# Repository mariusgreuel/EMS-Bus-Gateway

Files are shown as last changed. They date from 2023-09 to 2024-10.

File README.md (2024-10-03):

# EMS Bus Gateway

This repository contains a schematic and PCB layout of an **EMS Bus Gateway**. With the EMS Bus Gateway and the [EMS-ESP32](https://github.com/mariusgreuel/EMS-ESP32) firmware, you can connect EMS Bus devices, such as the **Buderus Logamax** boilers to your home automation system.

## Introduction

The assembled EMS Bus Gateway consists of three essential components:

- A voltage level converter that converts the EMS bus voltage levels to 3.3V TTL levels.
- A micro-controller.
- The EMS-ESP32 firmware.

The schematic uses a modified level convertor from the EMS reference schematic circulating the internet. For the micro-controller, a $5 [Seeed Studio XIAO ESP32C3](https://www.seeedstudio.com/Seeed-XIAO-ESP32C3-p-5431.html) board is used. The micro-controller needs to be programmed with [EMS-ESP32](https://github.com/mariusgreuel/EMS-ESP32) firmware, which is capable of decoding the EMS bus protocol and broadcasting the EMS parameters into your network via MQTT. Finally, the assembled board may be fitted into a **Hammond 1551KGY** enclosure.

The assembled EMS Bus Gateway board looks like this:

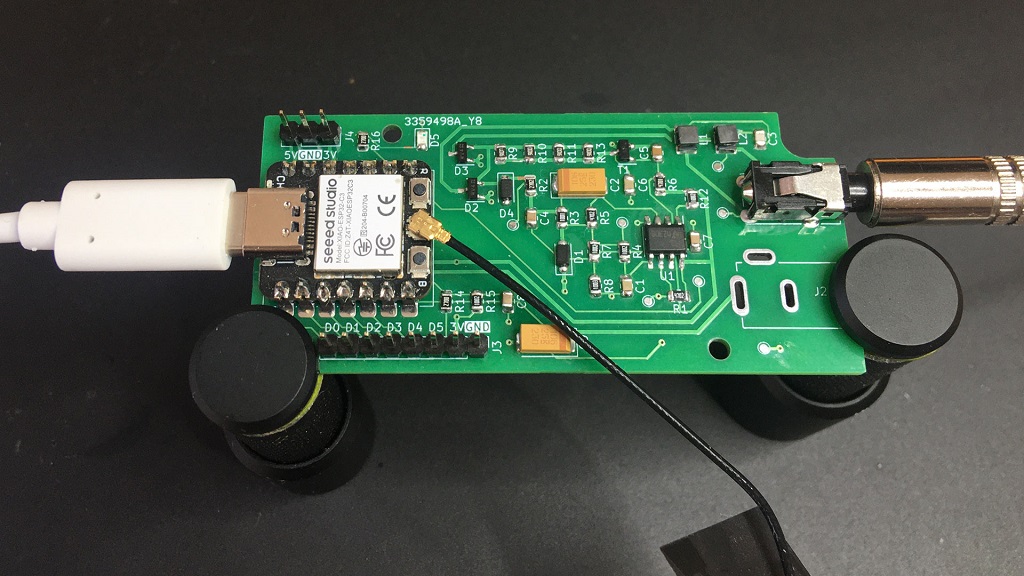
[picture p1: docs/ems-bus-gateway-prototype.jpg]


## EMS Bus Background

Many Buderus devices, such as the **Buderus Logamax plus GB132 T** boiler, use a bus system called **EMS (Energy Management System)** to communicate with other devices, such as the RC30 room controller. The EMS bus is a simple two-wire serial bus that uses voltage/current modulation to transmit data. With the proper hardware and software, you can transmit many parameters of your boiler into your home automation system.

For instance, you could use [Home Assistant](https://www.home-assistant.io/) to monitor the temperatures of your boiler. Here is a screenshot showing the relevant boiler temperatures during a 10 minutes heating interval:

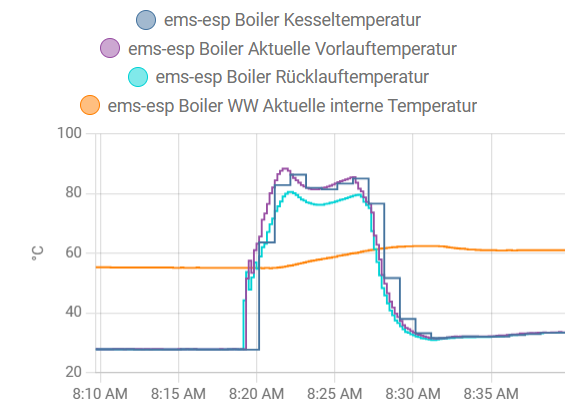
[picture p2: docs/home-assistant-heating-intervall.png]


## Build the EMS-ESP32 firmware

To build the EMS-ESP32 firmware, we use the **PlatformIO** toolchain. Please refer to the [PlatformIO documentation](https://docs.platformio.org/en/latest/) on how to install and use **PlatformIO**. According to the original author of the EMS-ESP32 firmware, your should build the firmware on Linux.

Instead of building the firmware locally, you may download pre-built binaries from my [EMS-ESP32 Releases](https://github.com/mariusgreuel/EMS-ESP32/releases).

To setup the **PlatformIO** toolchain, run the following commands in a Linux bash:

```bash
sudo apt install python3
python3 -m venv ~/.venv/ems-esp32
source ~/.venv/ems-esp32/bin/activate
curl -o- https://raw.githubusercontent.com/nvm-sh/nvm/v0.40.1/install.sh | bash
python -m pip install --upgrade pip
pip install platformio
pip install esptool
nvm install 18
nvm use 18
npm install --global yarn
git clone https://github.com/mariusgreuel/ems-esp32.git -b xiao-3.6.5 ~/repos/ems-esp32
```

To build the EMS-ESP32 firmware for a **XIAO ESP32C3**, run the following command:

```bash
source ~/.venv/ems-esp32/bin/activate
nvm use 18
cd ~/repos/ems-esp32
git clean -xdf
platformio run -e seeed_xiao_esp32c3
```

After the build is completed, you will find the binaries in the `.pio\build\seeed_xiao_esp32c3` or `.pio\build\seeed_xiao_esp32s3` folder.

## Flash the EMS-ESP32 firmware

To flash the EMS-ESP32 firmware on the XIAO ESP32, we use the **esptool.py** from Espressif. Please refer to the [Espressif documentation](https://docs.espressif.com/projects/esptool/en/latest/esp32/esptool/index.html) on how to install and use **esptool.py**.

To flash the EMS-ESP32 firmware on a **XIAO ESP32C3**, run the following command:

```bash
esptool.py --chip esp32c3 --port /dev/ttyUSB0 --baud 460800 --before=default_reset --after=hard_reset write_flash 0x0 bootloader.bin 0x8000 partitions.bin 0x10000 firmware.bin
```

## Configure the EMS-ESP32 software

> Note: The documentation below is a quick-start guide to setup the EMS gateway. For detailed instructions, refer to the original documentation at <https://emsesp.github.io/docs/>.

After you have flashed the XIAO ESP32, your need to configure the EMS-ESP32 software to connect it to your local WiFi network. Essentially, the EMS-ESP32 software creates a local WiFi access point that you can connect to. Then, you can open the dashboard of the EMS-ESP32 software using a web browser via a pre-defined username and password and connect the XIAO ESP32 to your local WiFi network:

- Connect the WSP to a USB-C power supply.
- Connect to the new WiFi access point **ems-esp** using the WPA password **ems-esp-neo**.
- Open the URL <http://ems-esp.local/> in a web browser.
- Enter the username **admin** and the password **admin**.

I recommend making the following configuration changes:

- Under **Settings**, set **Board profile** to **Seeed Studio XIAO ESP32C3**.
- Under **Network/Network Settings**, enter the SSID and password of your local WiFi network.
- Under **Access Point/Access Point Settings**, set **Enable Access Point** to **Never**. Before you disable the access point ensure that your EMS Bus gateway has successfully connected to your local WiFi network.
- Under **NTP/NTP Settings**, check **Enable NTP**.
- Under **MQTT/MQTT Settings**, enable MQTT, enter the IP address of your MQTT broker, and enter your MQTT broker credentials. If you run Home Assistant, check **Enable MQTT Discovery**, and set **Discovery Type** to **Home Assistant**.
- Under **Security**, create a new admin user and remove the pre-defined accounts.

As the EMS Bus Gateway is capable of manipulating the settings of your boiler and issuing arbitrary commands, I recommend putting the EMS gateway into **read-only mode**.

> WARNING: If you choose to not enable **read-only mode**, be advised that it is possible to issue powerful commands such starting up the heater of your boiler, which may potentially damage your boiler.

- Under **Settings**, check **Enable read-only mode**.

## Connect the EMS Bus Gateway to your boiler

To connect the EMS Bus Gateway to your boiler, first connect a USB power supply to the USB-C port of the XIAO ESP32. The XIAO ESP32 requires a power supply of 5V. Refer to the [XIAO ESP32C3 documentation](https://wiki.seeedstudio.com/XIAO_ESP32C3_Getting_Started/) for details.

To connect the gateway to the boiler, you can use a 3.5mm TRS audio cable to connect the connector of the EMS Bus Gateway to the service port of your boiler.

The pinout of the TRS service port connector and the EMS Bus Gateway connector is as follows:



Here is a picture of a Buderus Logamax plus GB132T Boiler with a RC30 controller.

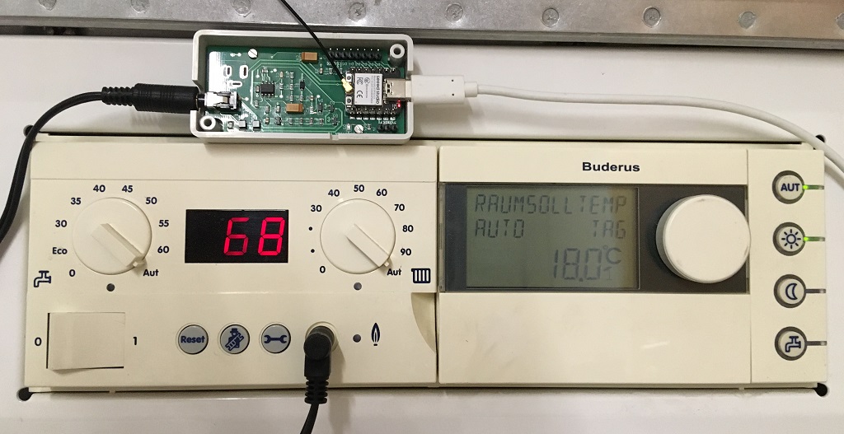
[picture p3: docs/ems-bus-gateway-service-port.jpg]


Instead of using the service port connector, you can connect a cable directly to the EMS front panel connector of your boiler. In this picture, the left orange/brown connector named **RC** (room controller) may be used. Refer to your boilers service manual for details. The polarity of this connector does not matter.

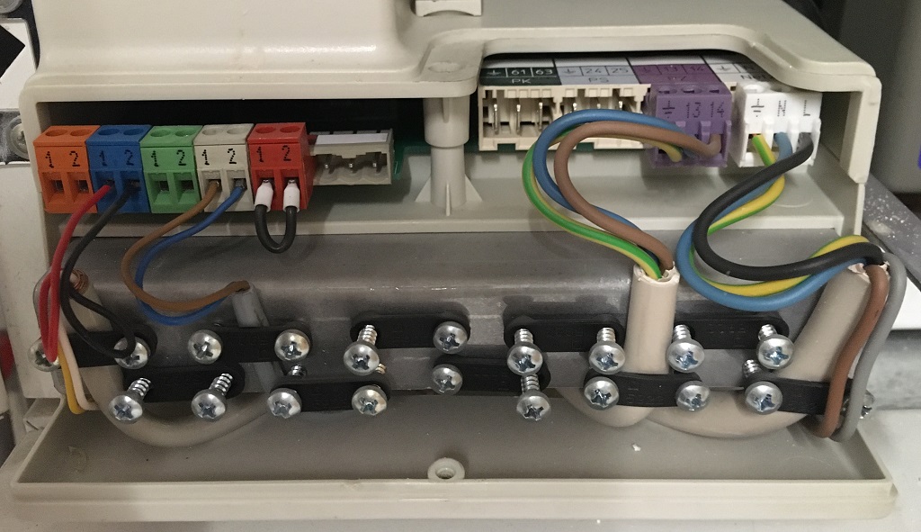
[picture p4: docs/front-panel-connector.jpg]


## Other documents in this repository

- [EMS Bus Gateway Rendering](./docs/ems-bus-gateway-rendering.jpg)
- [EMS Bus Gateway Schematic (PDF))](./docs/ems-bus-gateway-schematic.pdf)
- [EMS Bus Gateway Component Layout (PDF))](./docs/ems-bus-gateway-component-layout.pdf)
- [EMS Bus Gateway Component List (PDF))](./docs/ems-bus-gateway-component-list.pdf)
- [EMS Bus Gateway Gerber Files](./docs/ems-bus-gateway-gerber.zip)
- [EMS Bus Gateway KiCad project](./pcb)

## References

- EMS-ESP Firmware (EMS Bus Gateway Fork): <https://github.com/mariusgreuel/EMS-ESP32>
- EMS-ESP Firmware (Original): <https://github.com/emsesp/EMS-ESP32>
- EMS-ESP Firmware Documentation: <https://emsesp.github.io/docs/>
- Seeed Studio XIAO Documentation: <https://wiki.seeedstudio.com/SeeedStudio_XIAO_Series_Introduction/>

## License

The EMS Bus Gateway schematic, PCB layout, and documentation is released under the GNU GPLv3.

Copyright 2023 Marius Greuel.

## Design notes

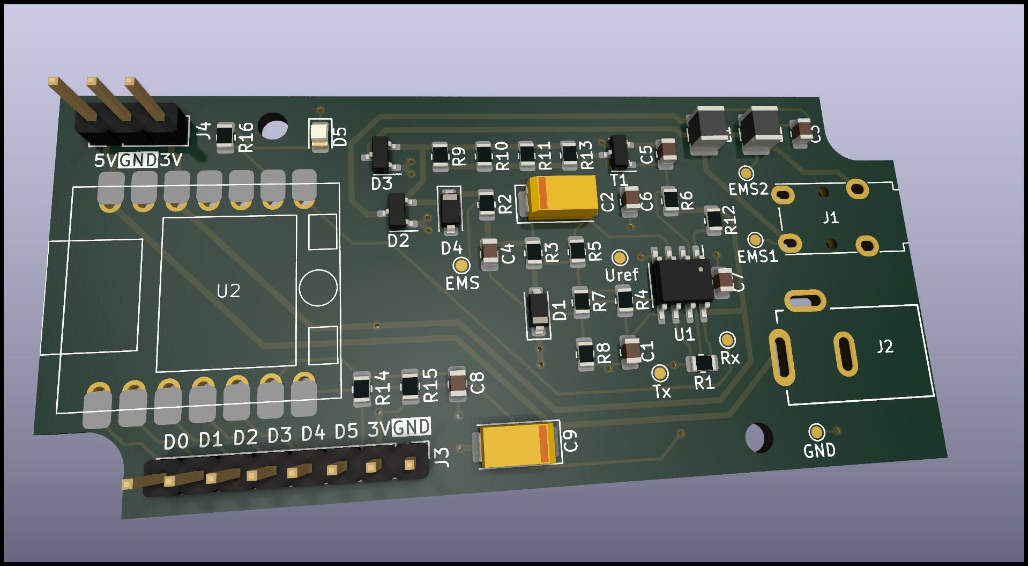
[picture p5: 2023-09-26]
docs/ems-bus-gateway-rendering.jpg

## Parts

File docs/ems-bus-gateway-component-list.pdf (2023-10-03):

Item | Qty Reference(s) | Value | LibPart
1 | 1 C1 | 10n | Device:C
2 | 2 C2, C9 | 10u | Device:C_Polarized
3 | 1 C3 | 68p | Device:C
4 | 2 C4, C5 | 1n | Device:C
5 | 1 C6 | 1.5n | Device:C
6 | 2 C7, C8 | 100n | Device:C
7 | 1 D1 | 1N4148 | Diode:1N4148
8 | 2 D2, D3 | BAT54S | Diode:BAT54S
9 | 1 D4 | BAT46 | Diode:BAT46
10 | 1 D5 | LED | Device:LED
11 | 2 H1, H2 | MountingHole | Mechanical:MountingHole
12 | 1 J1 | AudioJack3 | Connector:AudioJack3
13 | 1 J2 | Barrel_Jack_Switch | Connector:Barrel_Jack_Switch
14 | 1 J3 | Conn_01x08 | Connector_Generic:Conn_01x08
15 | 1 J4 | Conn_01x03 | Connector_Generic:Conn_01x03
16 | 2 L1, L2 | 4.7u | Device:L
17 | 2 R1, R5 | 47k | Device:R
18 | 1 R2 | 28k | Device:R
19 | 1 R3 | 1k | Device:R
20 | 4 R4, R7, R12, R15 | 10k | Device:R
21 | 1 R6 | 4K7 | Device:R
22 | 1 R8 | 100k | Device:R
23 | 4 R9, R10, R11, R13 | 910 | Device:R
24 | 1 R14 | 100 | Device:R
25 | 1 R16 | 150 | Device:R
26 | 1 T1 | BC847 | Transistor_BJT:BC847
27 | 1 TP1 | GND | Connector:TestPoint
28 | 1 TP2 | EMS1 | Connector:TestPoint
29 | 1 TP3 | EMS2 | Connector:TestPoint
30 | 1 TP4 | EMS | Connector:TestPoint
31 | 1 TP5 | Uref | Connector:TestPoint
32 | 1 TP6 | Tx | Connector:TestPoint
33 | 1 TP7 | Rx | Connector:TestPoint
34 | 1 U1 | LM393 | Comparator:LM393
35 | 1 U2 | XIAO-ESP32C3 | Project:XIAO-ESP32C3

Footprint
Capacitor_SMD:C_0805_2012Metric Capacitor_Tantalum_SMD:CP_EIA-6032-28_Kemet-C Capacitor_SMD:C_0805_2012Metric Capacitor_SMD:C_0805_2012Metric Capacitor_SMD:C_0805_2012Metric Capacitor_SMD:C_0805_2012Metric Diode_SMD:D_SOD-123
Package_TO_SOT_SMD:SOT-23
Diode_SMD:D_SOD-123
LED_SMD:LED_0805_2012Metric MountingHole:MountingHole_2.5mm Connector_Audio:Jack_3.5mm_Lumberg_1503_07_Horizontal Project:Lumberg-NEB-21-R
Connector_PinHeader_2.54mm:PinHeader_1x08_P2.54mm_Vertical Connector_PinHeader_2.54mm:PinHeader_1x03_P2.54mm_Vertical Inductor_SMD:L_1210_3225Metric Resistor_SMD:R_0805_2012Metric Resistor_SMD:R_0805_2012Metric Resistor_SMD:R_0805_2012Metric Resistor_SMD:R_0805_2012Metric Resistor_SMD:R_0805_2012Metric Resistor_SMD:R_0805_2012Metric Resistor_SMD:R_0805_2012Metric Resistor_SMD:R_0805_2012Metric Resistor_SMD:R_0805_2012Metric Package_TO_SOT_SMD:SOT-23
TestPoint:TestPoint_Pad_D1.0mm TestPoint:TestPoint_Pad_D1.0mm TestPoint:TestPoint_Pad_D1.0mm TestPoint:TestPoint_Pad_D1.0mm TestPoint:TestPoint_Pad_D1.0mm TestPoint:TestPoint_Pad_D1.0mm TestPoint:TestPoint_Pad_D1.0mm Package_SO:SO-8_3.9x4.9mm_P1.27mm Project:Seeed Studio XIAO

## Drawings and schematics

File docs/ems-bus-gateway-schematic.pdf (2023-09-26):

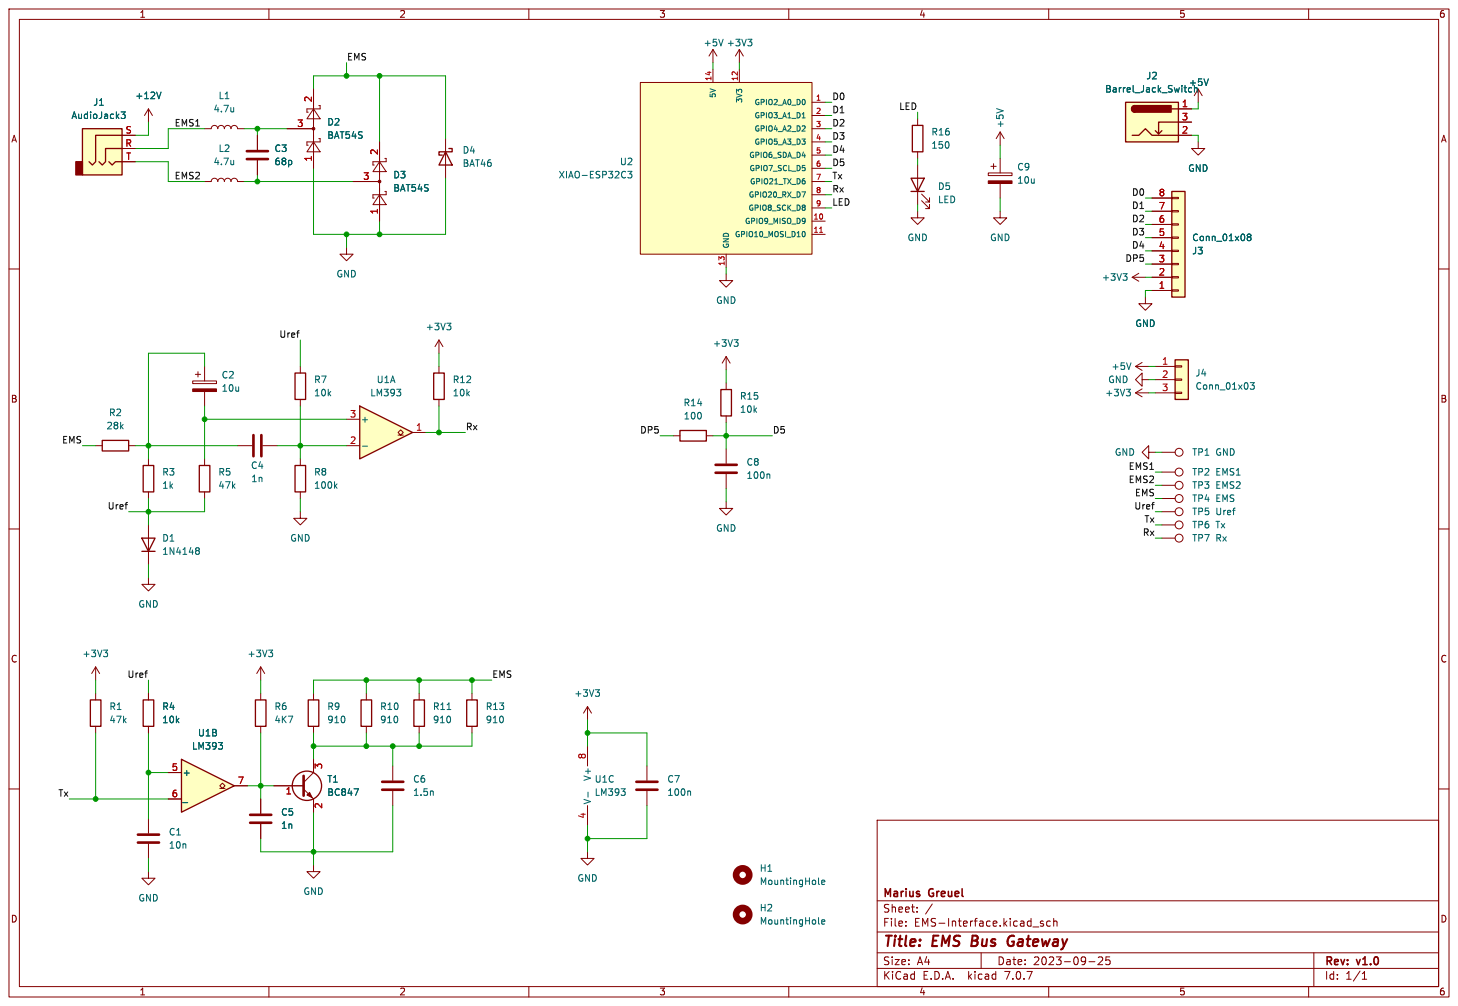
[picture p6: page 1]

File: EMS-Interface.kicad_sch Sheet: / Marius Greuel R9

Id: 1/1 Title: EMS Bus Gateway

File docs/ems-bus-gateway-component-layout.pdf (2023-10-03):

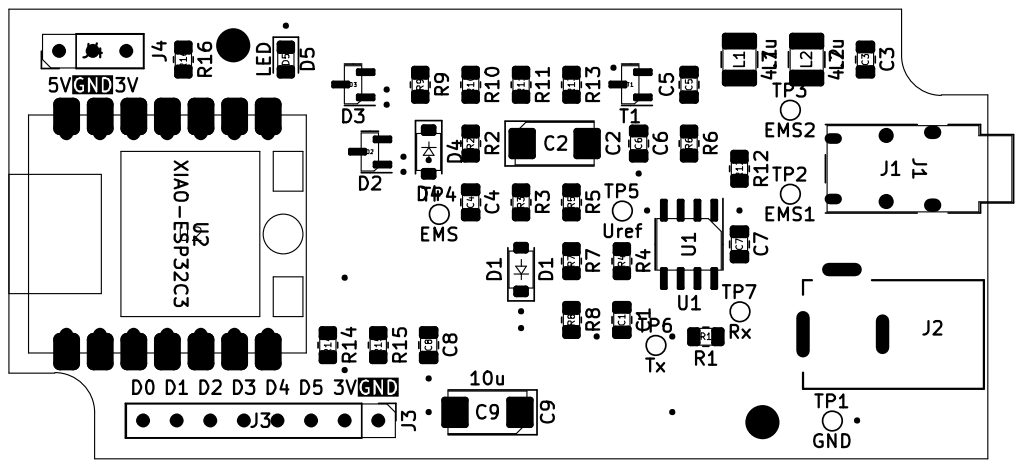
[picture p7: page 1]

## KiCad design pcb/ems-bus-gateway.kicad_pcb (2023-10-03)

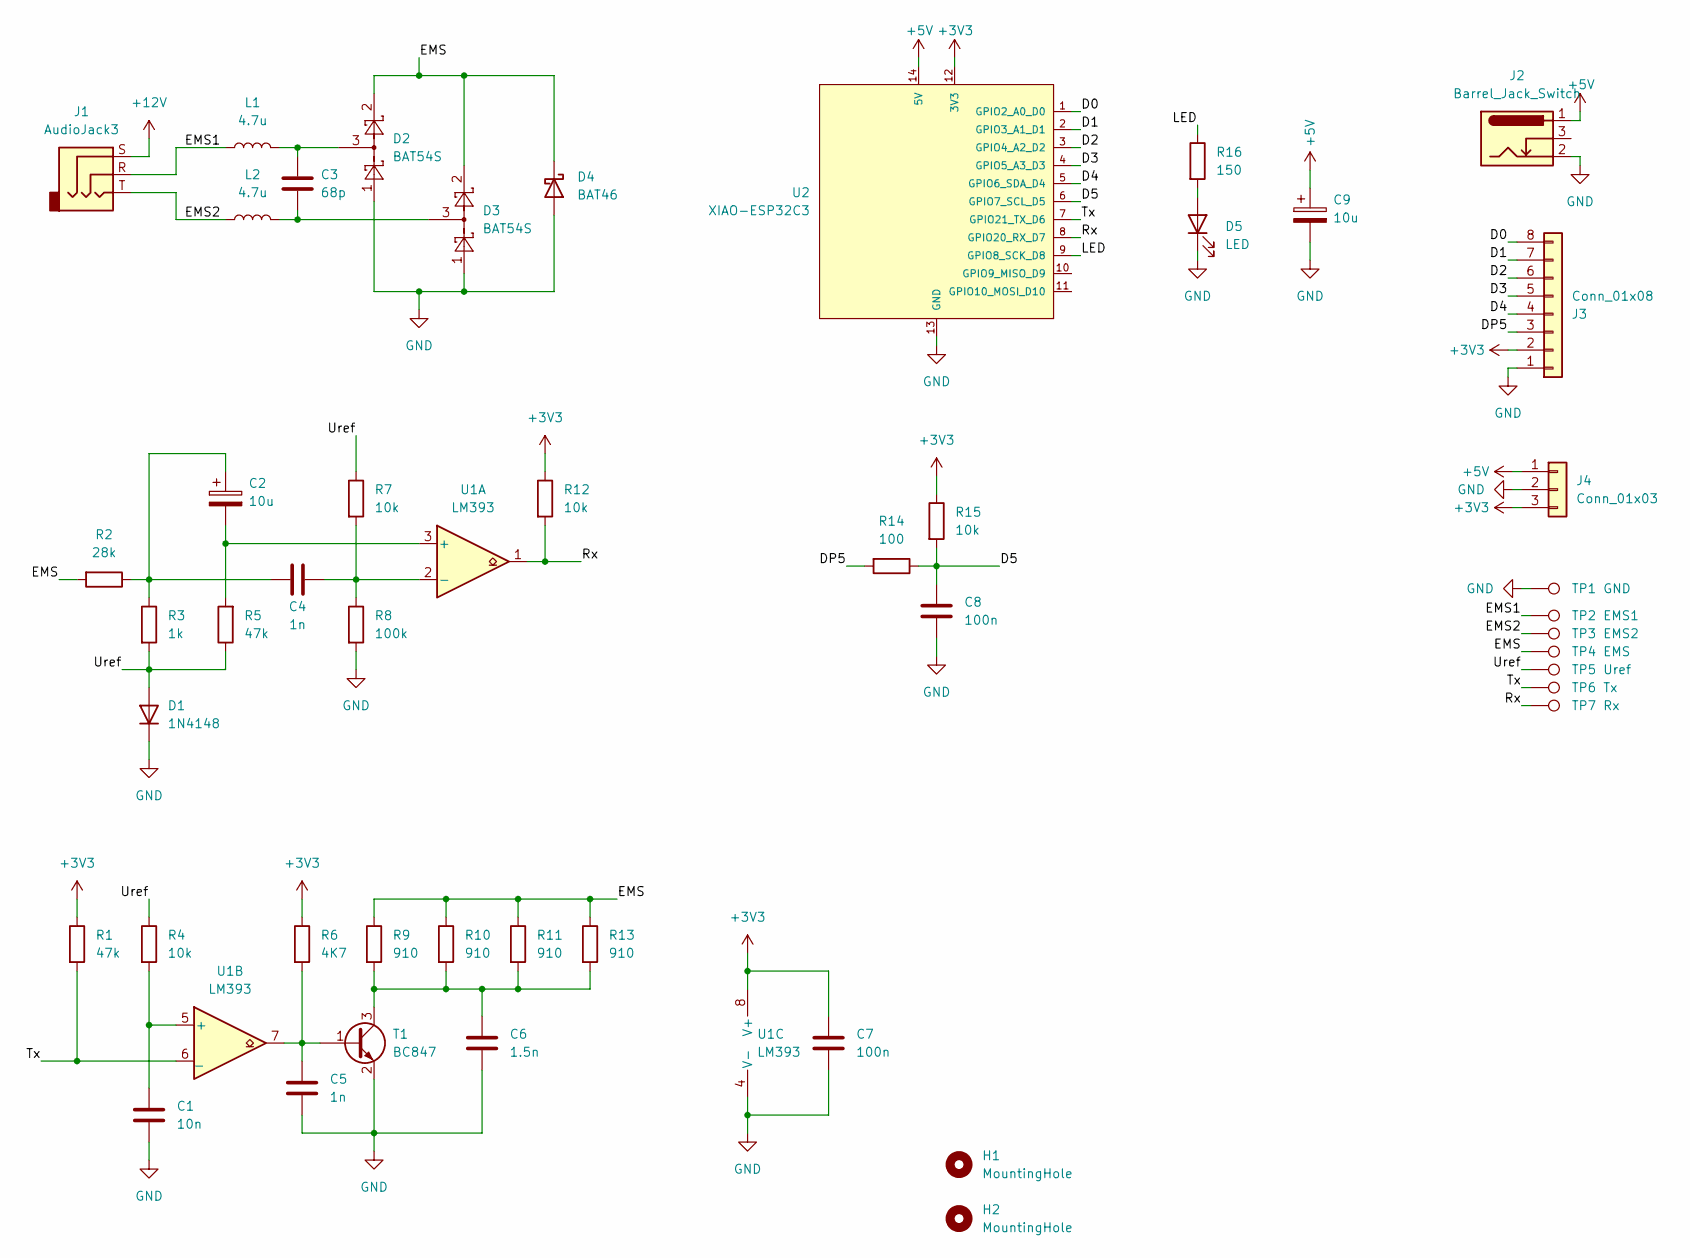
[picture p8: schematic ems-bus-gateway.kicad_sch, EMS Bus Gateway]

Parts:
C1: 10n; C_0805_2012Metric
C2, C9: 10u; CP_EIA-6032-28_Kemet-C
C3: 68p; C_0805_2012Metric
C4, C5: 1n; C_0805_2012Metric
C6: 1.5n; C_0805_2012Metric
C7, C8: 100n; C_0805_2012Metric
D1: 1N4148; D_SOD-123
D2, D3: BAT54S; SOT-23
D4: BAT46; D_SOD-123
D5: LED; LED_0805_2012Metric
H1, H2: MountingHole; MountingHole_2.5mm
J1: AudioJack3; Jack_3.5mm_Lumberg_1503_07_Horizontal
J2: Barrel_Jack_Switch; Lumberg-NEB-21-R
J3: Conn_01x08; PinHeader_1x08_P2.54mm_Vertical
J4: Conn_01x03; PinHeader_1x03_P2.54mm_Vertical
L1, L2: 4.7u; L_1210_3225Metric
R1, R5: 47k; R_0805_2012Metric
R2: 28k; R_0805_2012Metric
R3: 1k; R_0805_2012Metric
R4, R7, R12, R15: 10k; R_0805_2012Metric
R6: 4K7; R_0805_2012Metric
R8: 100k; R_0805_2012Metric
R9, R10, R11, R13: 910; R_0805_2012Metric
R14: 100; R_0805_2012Metric
R16: 150; R_0805_2012Metric
T1: BC847; SOT-23
TP1: GND; TestPoint_Pad_D1.0mm
TP2: EMS1; TestPoint_Pad_D1.0mm
TP3: EMS2; TestPoint_Pad_D1.0mm
TP4: EMS; TestPoint_Pad_D1.0mm
TP5: Uref; TestPoint_Pad_D1.0mm
TP6: Tx; TestPoint_Pad_D1.0mm
TP7: Rx; TestPoint_Pad_D1.0mm
U1: LM393; SO-8_3.9x4.9mm_P1.27mm
U2: XIAO-ESP32C3; Seeed Studio XIAO

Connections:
+3V3: C7.1, J3.2, J4.3, R1.1, R6.1, R12.1, R15.1, U1.8 (V+), U2.12 (3V3)
+5V: C9.1, J2.1, J4.1, U2.14 (5V)
+12V: J1.S
/D0: J3.8, U2.1 (GPIO2_A0_D0)
/D1: J3.7, U2.2 (GPIO3_A1_D1)
/D2: J3.6, U2.3 (GPIO4_A2_D2)
/D3: J3.5, U2.4 (GPIO5_A3_D3)
/D4: J3.4, U2.5 (GPIO6_SDA_D4)
/D5: C8.1, R14.1, R15.2, U2.6 (GPIO7_SCL_D5)
/DP5: J3.3, R14.2
/EMS: D2.2, D3.2, D4.1 (K), R2.2, R9.1, R10.1, R11.1, R13.1, TP4.1
/EMS1: J1.R, L1.1, TP2.1
/EMS2: J1.T, L2.1, TP3.1
/LED: R16.1, U2.9 (GPIO8_SCK_D8)
/Rx: R12.2, TP7.1, U1.1, U2.8 (GPIO20_RX_D7)
/Tx: R1.2, TP6.1, U1.6 (_), U2.7 (GPIO21_TX_D6)
/Uref: D1.2 (A), R3.2, R4.1, R5.1, R7.1, TP5.1
GND: C1.2, C5.2, C6.2, C7.2, C8.2, C9.2, D1.1 (K), D2.1, D3.1, D4.2 (A), D5.1 (K), J2.2, J3.1, J4.2, R8.2, T1.2 (E), TP1.1, U1.4 (V-), U2.13 (GND)
unnamed: C2.1, C4.2, R2.1, R3.1
unnamed: C3.1, D2.3, L1.2
unnamed: C3.2, D3.3, L2.2
unnamed: D5.2 (A), R16.2
unnamed: C5.1, R6.2, T1.1 (B), U1.7
unnamed: C6.1, R9.2, R10.2, R11.2, R13.2, T1.3 (C)
unnamed: C2.2, R5.2, U1.3 (+)
unnamed: C4.1, R7.2, R8.1, U1.2 (-)
unnamed: C1.1, R4.2, U1.5 (+)

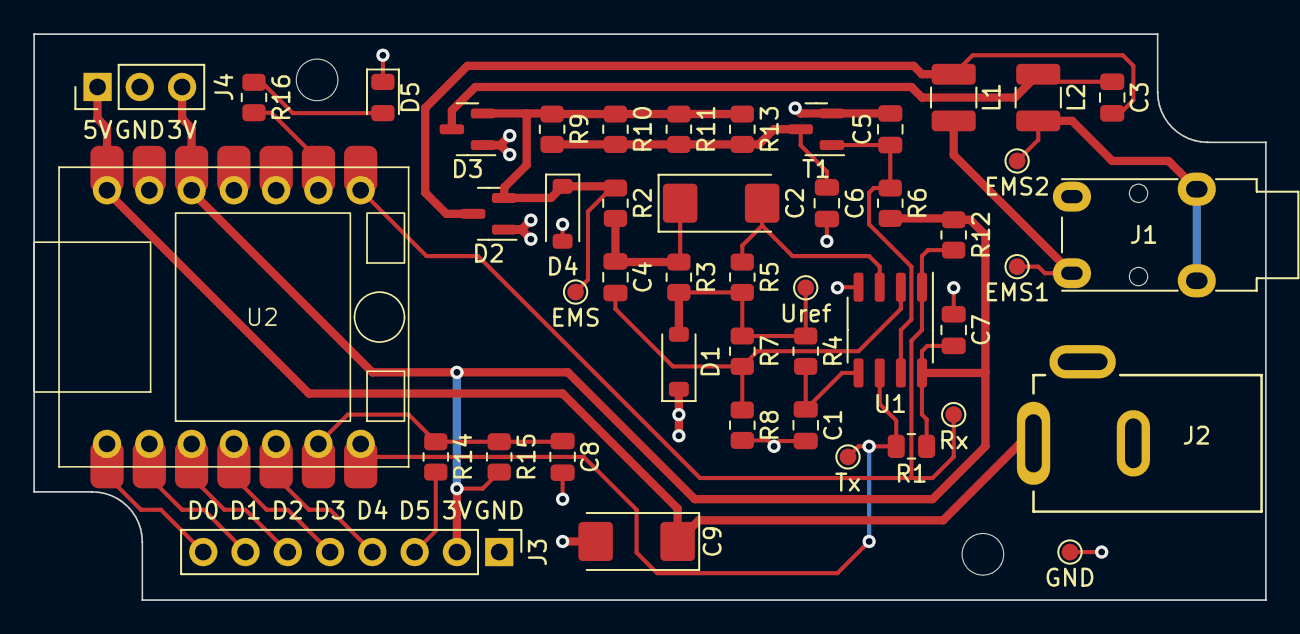
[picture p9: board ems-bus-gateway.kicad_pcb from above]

Board: 2 copper layers, 74.0 x 34.0 mm, 48 parts (0 on the bottom side), 26 nets.

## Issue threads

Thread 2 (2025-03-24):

Power via EMS Bus

micw, 2025-03-24:
Hello,

thank you for sharing this project. Do you think it's easily possible to power the entire unit via EMS Bus?

There are these small Buck-Convertes like https://de.aliexpress.com/item/1005003564766694.html. The bus has 9-12V, so Buck-Converting to 3V3 gives ~3x the max current - may be enough then to power the ESP32.

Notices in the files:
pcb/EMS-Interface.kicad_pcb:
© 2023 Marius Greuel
